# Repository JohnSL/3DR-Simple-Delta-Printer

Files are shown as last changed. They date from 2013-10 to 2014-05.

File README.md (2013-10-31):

3DR "Simple" Delta Printer
========================

This is a derivative of RichRap's 3DR Delta printer, but redesigned from scratch to be printable from a Printrbot Simple (hence the name), and to use the Simple's parts in order to build this printer. You can find his original files here: https://github.com/RichRap/3DR-Delta-Printer

Thank you for downloading, please be aware and abide by the license all these files are covered by - Attribution - ShareAlike Creative Commons V3 (CC BY-SA 3.0) - http://creativecommons.org/licenses/by-sa/3.0/

This License is not greatly restrictive at all, so please don't forget to attribute my work and acknowledge the work by others that this is built on.

Current Status
--------------
This is very much a work in progress. The SolidWorks files are built with version 2011, and represent a work in progress. The original STL files I checked in are what I've built so far.

You can follow me in two places:

My Blog: http://trains.socha.com  
RepRap Forums: http://forums.reprap.org/read.php?178,244826

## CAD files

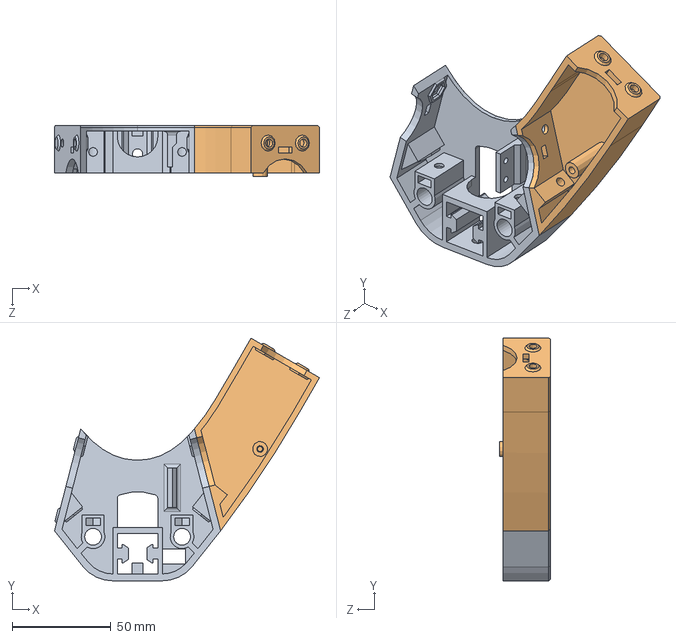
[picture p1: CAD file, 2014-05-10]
SolidWorks/Bottom Triangle Assembly.SLDASM
134.0 x 122.7 x 26.0 mm
3DR Bottom Motor Mount
Wings

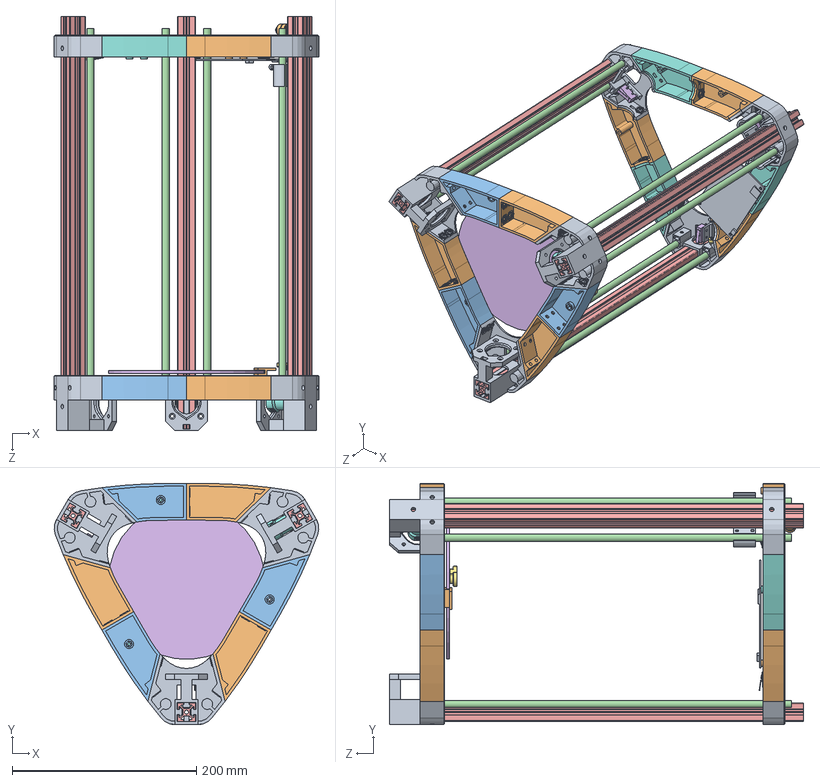
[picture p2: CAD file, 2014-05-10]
SolidWorks/3DR Simple Delta Printer.SLDASM
287.6 x 262.1 x 450.0 mm
3DR Bottom Motor Mount x 6
Wings x 6
Wing Mirror Long x 3
RGOCG8-400 x 6
HFSB5-2020-450 x 3
Round Plate
Spool
Carriage for LM8UU
624ZZ x 2
Nut
Washer x 3
Button Head Screw
Microswitch x 3
Cap Head Screw x 3
Wing Mirror Long Top x 3
Printrboard
Bed Clip

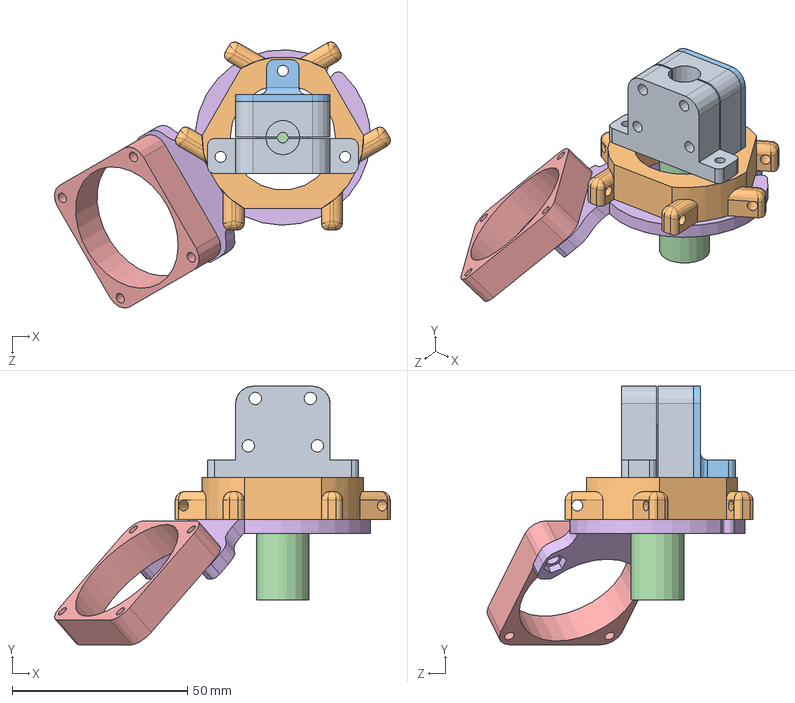
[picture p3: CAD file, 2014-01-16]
SolidWorks/Effector And Hot End.SLDASM
95.8 x 73.7 x 75.9 mm
Hot End Holder x 2
Platform
Hot End Plate
Hot End
Fan
Fan and LED Mount

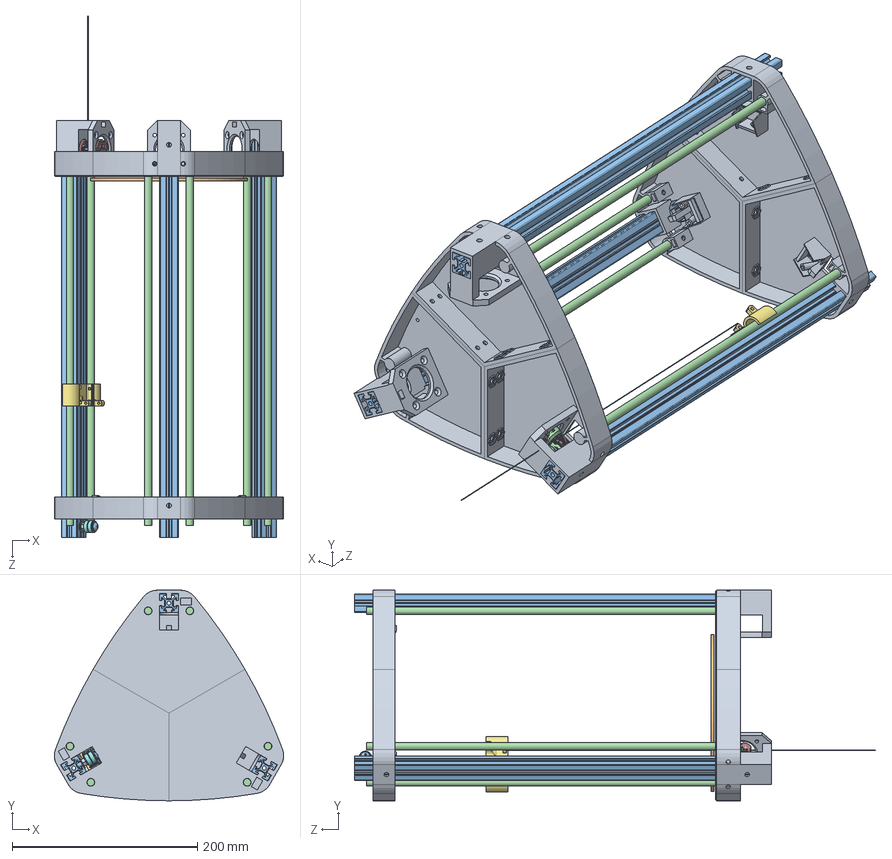
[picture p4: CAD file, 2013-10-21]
SolidWorks/3DR Delta Printer.SLDASM
247.5 x 227.4 x 562.6 mm
3DR Bottom Motor Mount x 6
Round Plate
HFSB5-2020-450 x 3
RGOCG8-400 x 6
Carriage for LM8UU
624ZZ x 2
Nut
Washer x 3
Button Head Screw x 4
Spool

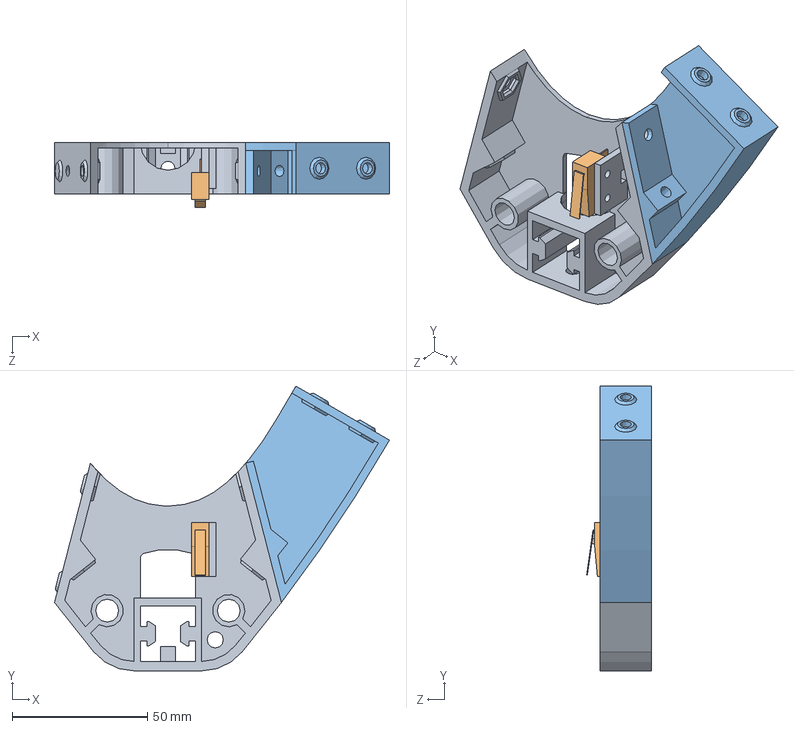
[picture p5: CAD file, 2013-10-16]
SolidWorks/Top Triangle Assembly.SLDASM
124.0 x 105.4 x 24.0 mm
3DR Bottom Motor Mount
Microswitch
Wings

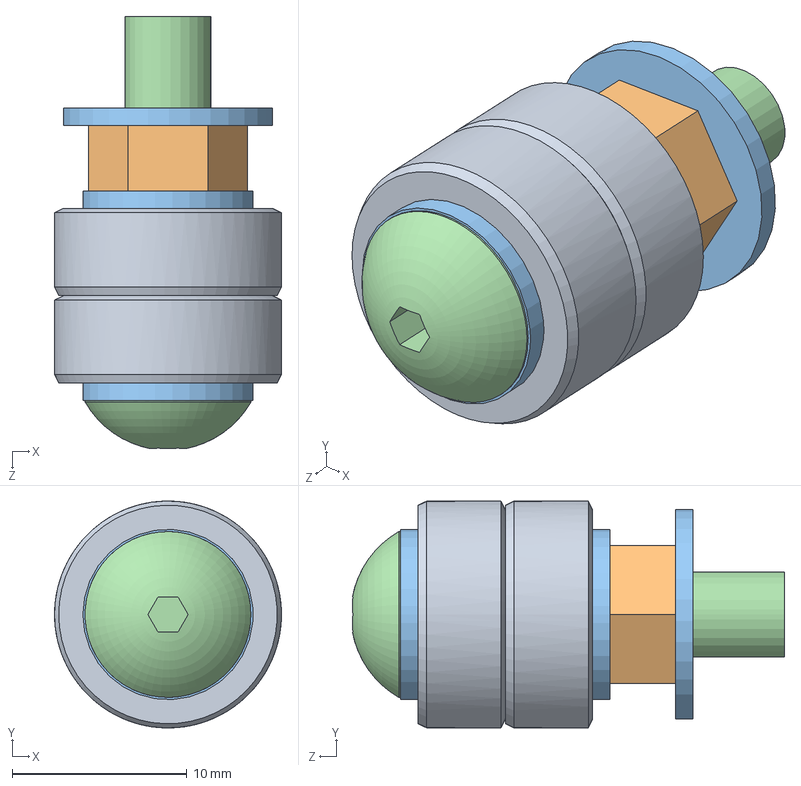
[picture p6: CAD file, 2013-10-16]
SolidWorks/Spectra Idler.SLDASM
13.0 x 13.0 x 24.8 mm
624ZZ x 2
Nut
Washer x 3
Button Head Screw

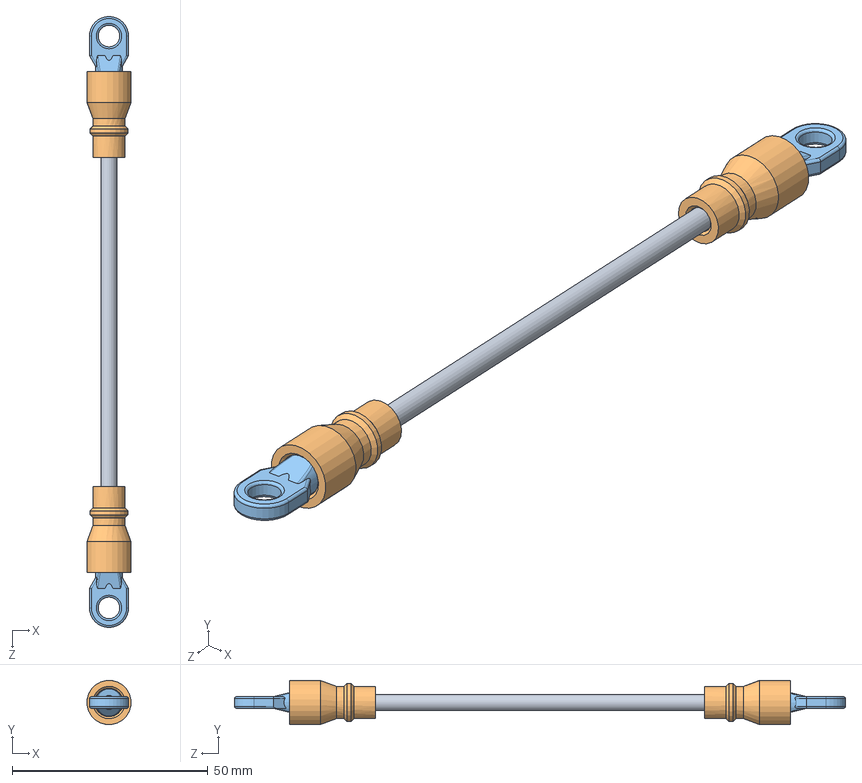
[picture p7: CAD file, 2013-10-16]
SolidWorks/Rod Assembly.SLDASM
11.3 x 11.3 x 156.0 mm
Carbon Rod
Bearing Shaft Coupler x 2
Rod Ends x 2

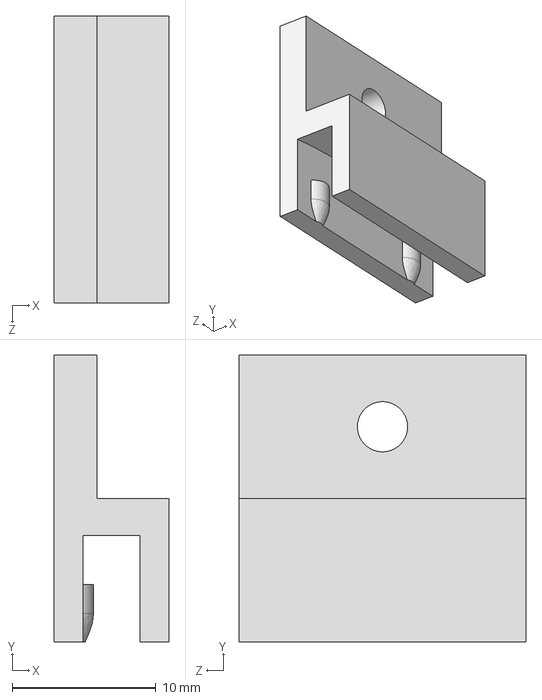
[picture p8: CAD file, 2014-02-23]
STEP/Bed Clip.STEP
8.00 x 20.0 x 20.0 mm

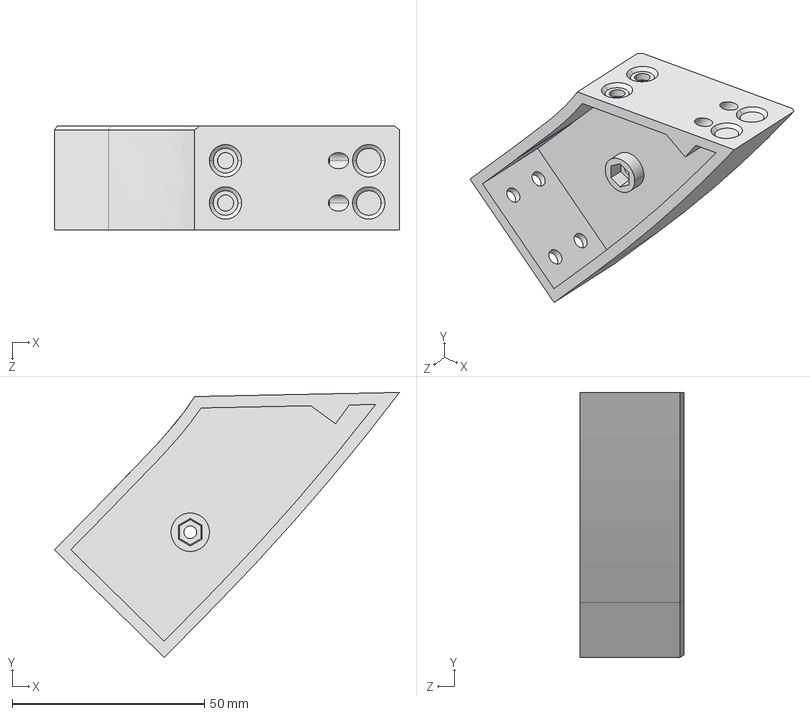
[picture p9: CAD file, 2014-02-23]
STEP/Bottom/Wing Mirror Long.STEP
89.7 x 69.0 x 27.0 mm

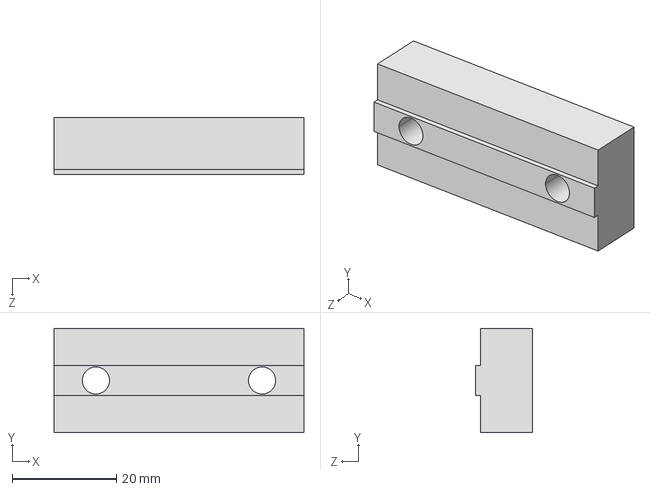
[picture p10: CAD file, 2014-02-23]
STEP/Extruder/Extruder Spacer.STEP
48.0 x 20.0 x 11.0 mm

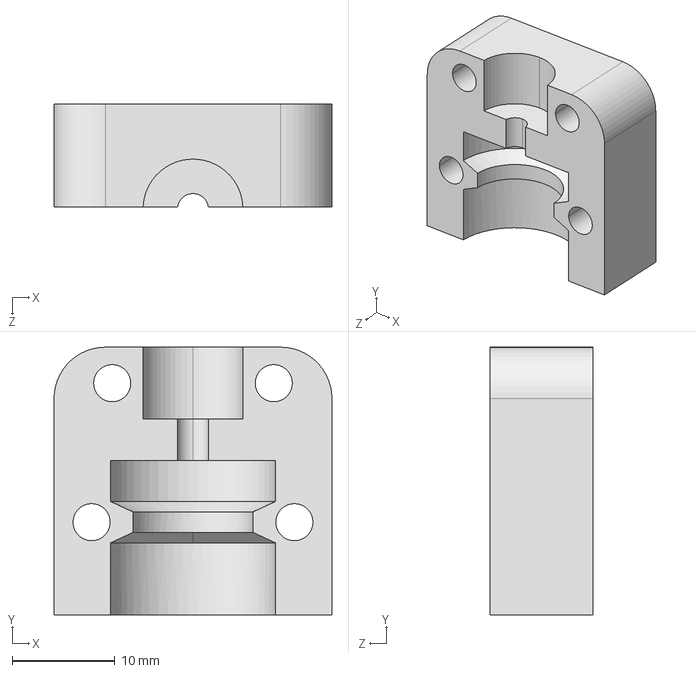
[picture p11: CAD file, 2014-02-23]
STEP/Hot End/Hot End Holder.STEP
27.0 x 26.0 x 10.0 mm

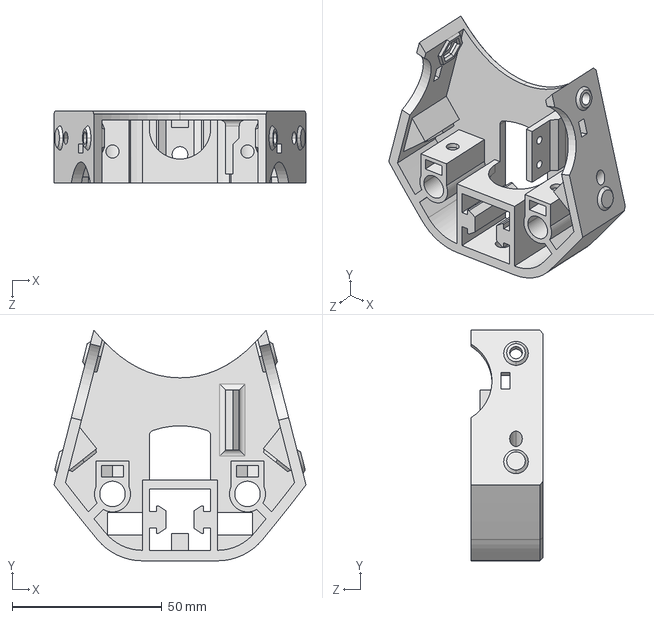
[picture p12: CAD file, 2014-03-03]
STEP/Top/3DR Bottom Motor Mount.STEP
84.0 x 76.9 x 24.0 mm

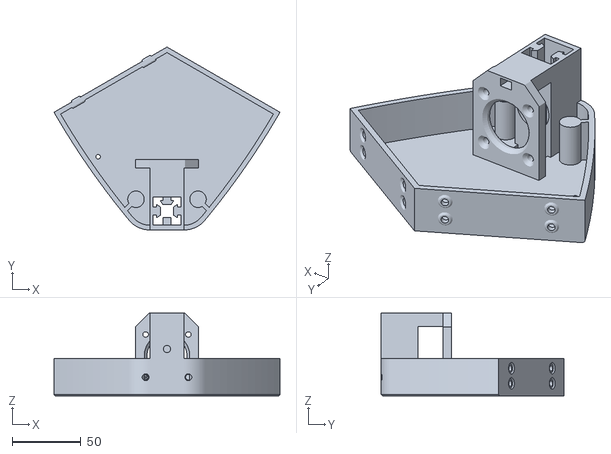
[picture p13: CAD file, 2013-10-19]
STL/Full Parts/3DR Bottom Motor Mount.STL
164.0 x 132.8 x 60.0

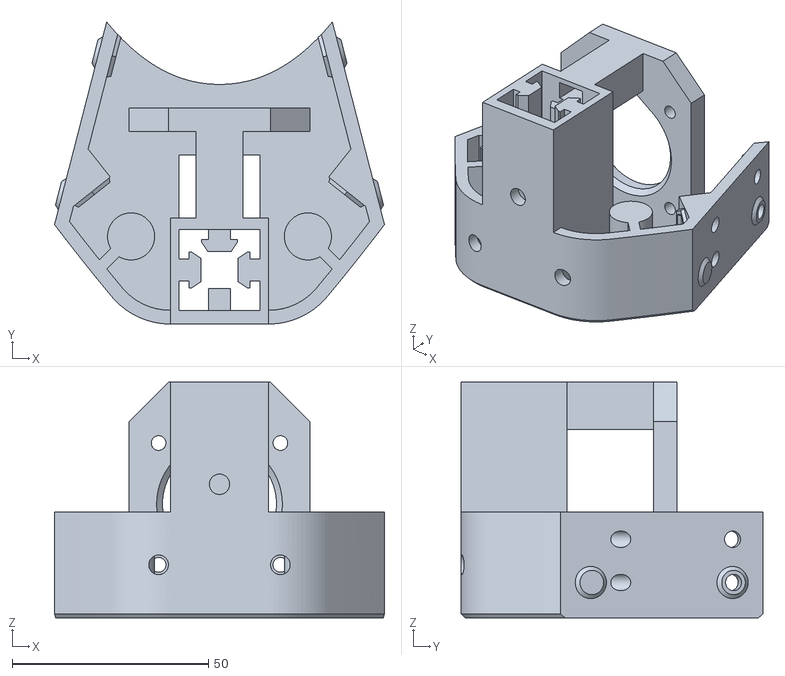
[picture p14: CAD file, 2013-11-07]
STL/Simple Parts/3DR Bottom Motor Mount Simple.STL
84.0 x 76.9 x 60.0

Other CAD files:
STL/Spiral Bed Clamp Tall.STL
SolidWorks/FSR Platform.SLDPRT
STEP/Bearing Shaft Coupler.STEP
STEP/Bottom/3DR Bottom Motor Mount.STEP
STEP/Bottom/Wings.STEP
STEP/Carriage for LM8UU.STEP
STEP/Hot End/Effector And Hot End.STEP
STEP/Hot End/Fan and LED Mount.STEP
STEP/Hot End/Hot End Holder Tabs.STEP
STEP/Hot End/Hot End Plate.STEP
STEP/Hot End/Platform.STEP
STEP/Top/Wing Mirror Long Top.STEP
STEP/Top/Wings with Power.STEP
STEP/Top/Wings.STEP
STL/2020extrusion_cap-nohole.stl
STL/Bearing Shaft Coupler.STL
STL/Bed Clip.STL
STL/Bed Holder.STL
STL/Carbon Rod Jig.STL
STL/Carriage for LM8UU.STL
STL/Extruder/Extruder Spacer.STL
STL/FSR Platform.STL
STL/Hot End/Fan and LED Mount.STL
STL/Hot End/Hot End Holder Tabs.STL
STL/Hot End/Hot End Holder.STL
STL/Hot End/Hot End Plate.STL
STL/Hot End/Platform.STL
STL/Rod Tensioner.STL
STL/Simple Parts/Wing Mirror Long.STL
STL/Simple Parts/Wings.STL
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

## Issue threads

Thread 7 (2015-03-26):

Maximum height without distortions

orangeudav, 2015-03-26:
What maximum height of printer you are recommend for 20x20mm extrusion and 8mm rod?
BTW, http://www.thingiverse.com/thing:646708 ! What you think about?

darconeous, 2016-06-22:
My 3DS is about as tall as is practical. It has a max unclipped build cylinder with a height of 400mm and a diameter of 140mm. Any taller and you end up having oscillation issues.

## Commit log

2013-10-16 The first check-in of all files
    This contains SolidWorks 2011 files, as well as exported STL files for
    the current versions of the design.
    [3DR Bottom Center Foot.SLDPRT, 3DR Bottom Center Foot.STL, 3DR Bottom Motor Mount Simple.STL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]
2013-10-17 Strong bottom and first hot-end mount
    I modified the design of the bottom parts to make them much stiffer,
    both by adding a fourth wall, and adding another row of screws.
    I also shrank the effector, and then created the first design for a
    hot-end mount.
    [3DR Simple Delta Printer - Copy.SLDASM, Bottom Triangle Assembly.SLDASM, Carriage for LM8UU.STL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]
2013-10-19 Bottom Triangle
    I created two new folders:
    Full Parts: These are like the 3DR, and require a larger printer
    Simple Parts: Small enough to print a Printrbot Simple
    [3DR Bottom Center Foot.STL, 3DR Bottom Motor Mount Simple.STL, 3DR Bottom Motor Mount.STL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]
2013-10-21 More room for spools, and fixes
    Moved the motor mounts farther from extrusion to allow more room for the
    spindle. Also made the spindle hole larger, and oblong instead of round.
    Finally, fixed up various configurations.
    [3DR Delta Printer.SLDASM, 3DR Simple Delta Printer.SLDASM, Bed Holder.SLDPRT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]
2013-10-31 Wider to use full build plate
    * Made the wings longer to use more of the build plate
    * Added slots in top parts for routing and securing wires
    * Increased gap between micro switch mount and rod holder
    [3DR Simple Delta Printer.SLDASM, Bottom Triangle Assembly.SLDASM, MirrorWings.SLDPRT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]
2013-11-02 Finished bottom parts.
    Started printing the bottom parts for the new design. This check-in
    includes the updated STL files for the bottom, as well as an initial
    design for a new bed clip that will allow leveling the bed. I also added
    the hole in the long wing for the bed clips.
    [3DR Bottom Motor Mount Simple.STL, 3DR Simple Delta Printer.SLDASM, Bed Clip.SLDPRT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]
2013-11-07 Stronger spool
    * Modified the spool to be much stronger
    [3DR Bottom Motor Mount Simple.STL, 3DR Simple Delta Printer.SLDASM, Bottom Triangle Assembly.SLDASM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]
2013-11-07 Finished top parts
    Added the bosses to hold the Printrboard to the top, and created the STL
    files for the top.
    [3DR Bottom Motor Mount.STL, 3DR Simple Delta Printer.SLDASM, Bottom Triangle Assembly.SLDASM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]
2013-11-20 Final set of version 2 changes
    This includes the updated hot-end parts to make them stronger, and to
    allow complete motion of the joints (before there was some binding).
    These files represent what I've built so far.
    [3DR Bottom Motor Mount.STL, 3DR Simple Delta Printer.SLDASM, Bottom Triangle Assembly.SLDASM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]
2013-11-30 Acrylic plate, extruder spacer, and fan mount
    Adding a design for a laser-cut acrylic plate that doesn't need mounting
    clips. Also added an extruder spacer so it won't hit the carriage.
    Finally, added a preliminary fan and LED mount (just the fan so far).
    [3DR Simple Delta Printer.SLDASM, Acrylic Plate.DWG, Acrylic Plate.SLDPRT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]
2013-11-30 End Caps
    Adding the end caps I used, from http://www.thingiverse.com/thing:45339
    [2020extrusion_cap-nohole.stl, MirrorWings.STL, misumi_2020_extrusion_cap two Ts.stl]
2014-01-16 Small Updates
    Removed a couple of STL files that shouldn't have been added. Also made
    minor updates to parts.
    [3DR Top Mount.STL, Effector And Hot End.SLDASM, Fan and LED Mount.SLDPRT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]
2014-02-23 Adding STEP files
    Adding STEP files to allow modifying the files.
    [3DR Bottom Motor Mount.STEP, Bearing Shaft Coupler.STEP, Bed Clip.STEP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]
2014-03-03 Added fillet to screw boss on top wing parts
    [3DR Simple Delta Printer.SLDASM, Bottom Triangle Assembly.SLDASM, Wing Mirror Long Top.SLDPRT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]
2014-03-03 Added a second slot for stepper wires
    I added a second slot on the other side for the stepper wires on the top
    motor mount. This allows routing the wires on the side without the end
    stop, which makes it a lot easier to route the wires.
    [3DR Bottom Motor Mount.STEP, 3DR Bottom Motor Mount.STL, 3DR Simple Delta Printer.SLDASM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]
2014-05-10 Strengthened the power connector on the top wing
    [3DR Simple Delta Printer.SLDASM, Bottom Triangle Assembly.SLDASM, FSR Platform.SLDPRT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]
